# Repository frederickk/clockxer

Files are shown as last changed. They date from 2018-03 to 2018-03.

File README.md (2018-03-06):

Clockxer
======

### An analog sync clock with adjustable BPM and 2-channel passive mixer.

------
#### 💾 Software

Under the hood is an [Arduino Uno](https://store.arduino.cc/usa/arduino-uno-rev3) along with a [SparkFun Spectrum Shield](https://www.sparkfun.com/products/13116) ~~(for audio analysis)~~. Both of these are probably a bit overkill given the way I'm implementing things. But, I'm more comfortable with software than hardware and I had an Arduino sitting idle on my desk.

The Arduino handles the logic for reading the values from the rotary encoder ~~and analyzing the audio data for beat detection~~ (TODO 😄). There are two libraries that I leaned on for this.

**Third party libraries**
* [MSGEQ7](https://github.com/NicoHood/MSGEQ7) which makes it much easier to pull audio data from the [MSGEQ7](https://www.sparkfun.com/datasheets/Components/General/MSGEQ7.pdf) chips which are part of the [Spectrum Shield](https://www.sparkfun.com/products/13116).
* [Adafruit LED Backpack](https://github.com/adafruit/Adafruit_LED_Backpack) which handles all of the magic to display BPM value on the segment display.
* [Protothreads library](https://code.google.com/archive/p/arduinode/downloads) A library for manaing [protothreads](http://harteware.blogspot.com/2010/11/protothread-powerfull-library.html) for Arduino.

------
#### 🎛️ Hardware

The hardware for this is pretty simple to put together. However, I can nearly guarantee that the way I've done it is not the most efficient way. For example, the [Spectrum Shield](https://www.sparkfun.com/products/13116) is a bit overkill and I could have use a singular MSGEQ7 IC. Equally, the Arduino itself is probably unnecessary for an actual electrical engineer. If you have suggestions, make a [pull request]() 🙏. Within the [hardware]() folder you'll find [Fritzing]() schematic files (or consult the JPEG below).

| Line-in (source) | Line-in | BPM | Sync | Mix |
| --- | --- | --- | --- | --- |
| Input: This audio analyzed by the MSGEQ7 chips, passed through to the **sync** output, and merged with **line-in** input. | Input: is passed through and merged with **source** input. | Knob: Set BPM for **sync** output. Push to toggle whether **sync** output is active. | Output: A 5V PP signal for syncing analog devices to the given BPM. | Output: Merged audio (mono) signal of **source** and **line-in** inputs. |
| Volume: Adjust the volume of the **source** input. | Volume: Adjust the volume of the **line-in** input. | | | Volume: Adjust the volume of the **mix** output. |

**Schematic**
How to solder everything together.

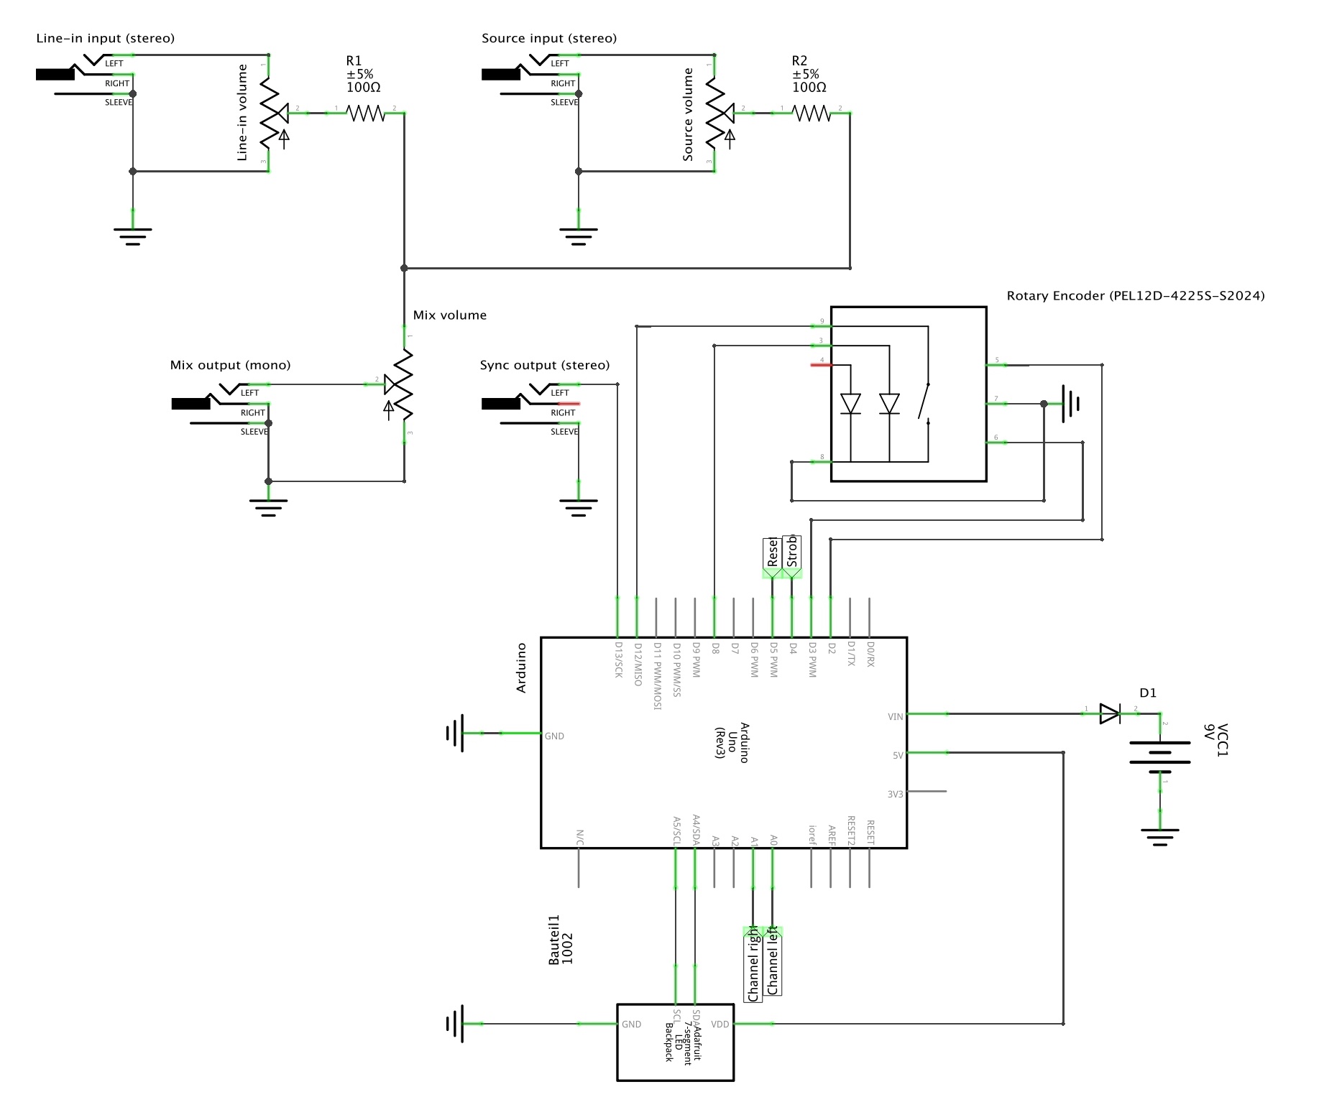
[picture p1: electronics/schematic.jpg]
Schematic


**Parts list**
The components for this project can be obtained through a few sources [Arduino](https://arduino.cc), [Adafruit](https://adafruit.com), [Sparkfun](https://sparkfun.com), and [DigiKey](https://digikey.com).

| Qty  | Part | Ref No. |
| ---- | --- | --- |
| 1 | Arduino Uno | |
| 1 | Spectrum Shield | [DEV-13116](https://www.sparkfun.com/products/13116) |
| 1 | Enclosure 119.5mm x 94mm x 42mm | [1590BBSBK](https://www.digikey.com/scripts/DkSearch/dksus.dll?Detail&itemSeq=251416092&uq=636536516904889851) |
| 1 | Rotary Encoder switch and LED | [PEL12D-4225S-S2024](https://www.digikey.com/scripts/DkSearch/dksus.dll?Detail&itemSeq=251416645&uq=636536516904889851) |
| 1 | Transparent knob | [COM-10597](https://www.digikey.com/scripts/DkSearch/dksus.dll?Detail&itemSeq=251417859&uq=636536516904899851) |
| 3 | 10k Logarithmic Potentiometer | [PDB181-K420K-103A2](https://www.digikey.com/scripts/DkSearch/dksus.dll?Detail&itemSeq=251416999&uq=636536516904889851) |
| 3 | Volume knob | [1568-1606](https://www.digikey.com/scripts/DkSearch/dksus.dll?Detail&itemSeq=251417794&uq=636536516904889851) |
| 3 | 1/4" (6.35mm) Stereo input jack | [SC1317](https://www.digikey.com/product-detail/en/switchcraft-inc/112BX/SC1317-ND/1217816) |
| 1 | 4-Digit 7-Segment Display w/I2C Backpack | [1002](https://www.adafruit.com/product/1002) |
| 1 | 9V Connector | [36-232](https://www.digikey.com/product-detail/en/keystone-electronics/232/36-232-ND/303804) |
| 1 | 50V 1A Diode (1N4001) | [641-1310-1](https://www.digikey.com/product-detail/en/comchip-technology/1N4001-G/641-1310-1-ND/1979675) |

**Enclosure**

Of course you can use any enclosure you want, but I opted for a [diecast aluminium (black) case](https://www.digikey.com/product-detail/en/hammond-manufacturing/1590BBSBK/1590BBSBK-ND/3869214). It's compact (119.5mm x 94mm x 42mm), but still has plenty of room for the Arduino and a 9-volt battery. I've created a [base](https://www.tinkercad.com/things/crAZhWdCvB1-clockxer-enclosure-base) that sits inside the enclosure to keep the internal components in place. For mounting the 7 Segment display I've created a [cowling](https://www.tinkercad.com/things/hzLmspQi8GF-clockxer-led-cowling) to mask the terribly cut square hole.

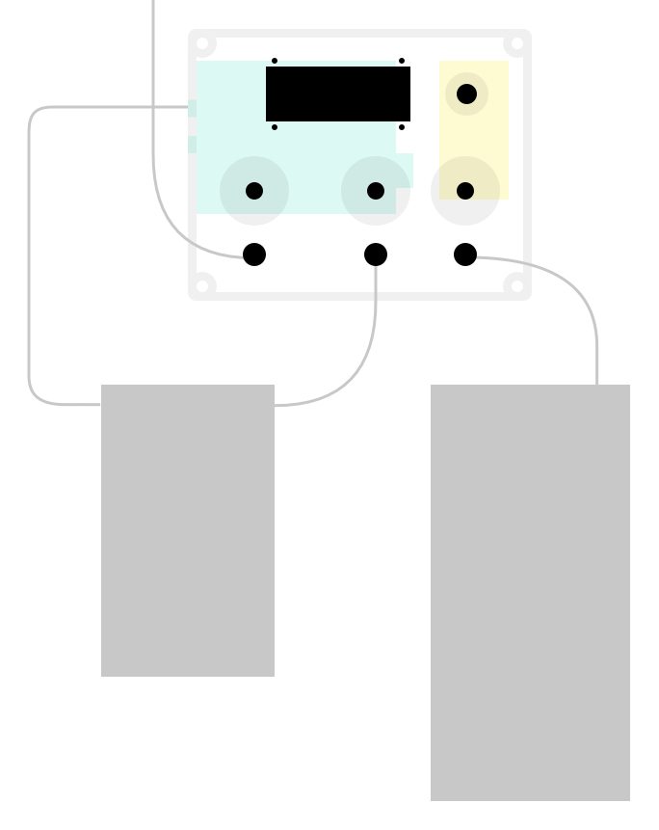
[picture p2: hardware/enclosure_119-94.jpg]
Enclosure layout


------
#### 🎩 Tip-of-the-hat

Without [Google](https://google.com) I wouldn't have stumbled across the following sites, which were helpful in a number of ways.

* [Electronoize Playshop: Dividers, Volume Controls, Mixers, Filters, Switches...](http://www.fluxmonkey.com/electronoize/passiveDividersFilters.htm)
* [Timer, Counter und Interrupts | heise Developer](https://www.heise.de/developer/artikel/Timer-Counter-und-Interrupts-3273309.html)
* [bildr  » Rotary Encoder + Arduino](http://bildr.org/2012/08/rotary-encoder-arduino/)
* [How to "Multithread" an Arduino (Protothreading Tutorial)](https://create.arduino.cc/projecthub/reanimationxp/how-to-multithread-an-arduino-protothreading-tutorial-dd2c37)
* [protothread, a powerfull library[sic]](http://harteware.blogspot.com/2010/11/protothread-powerfull-library.html)

------
#### 📜 License

[MIT](https://opensource.org/licenses/MIT)

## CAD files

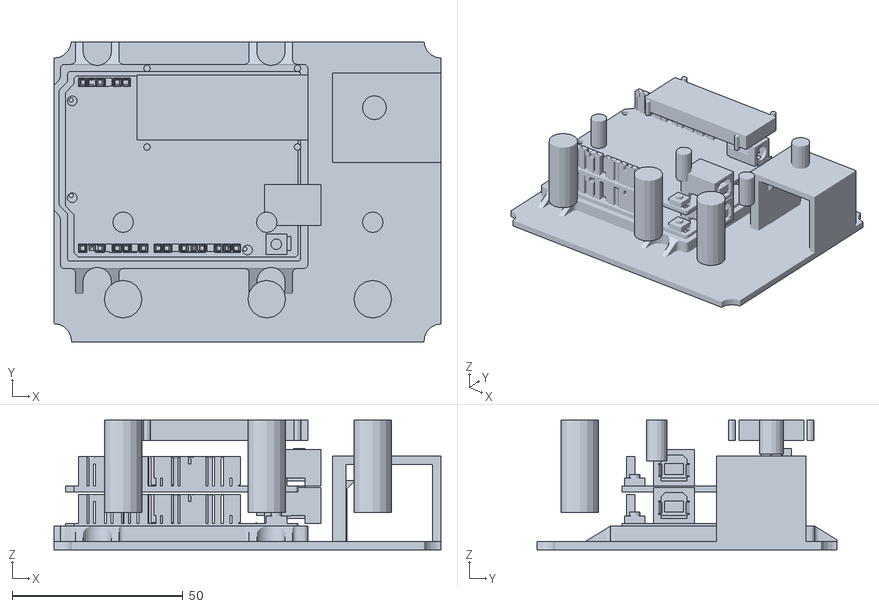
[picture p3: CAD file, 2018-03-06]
hardware/enclosure-base.stl
113.2 x 87.7 x 38.0

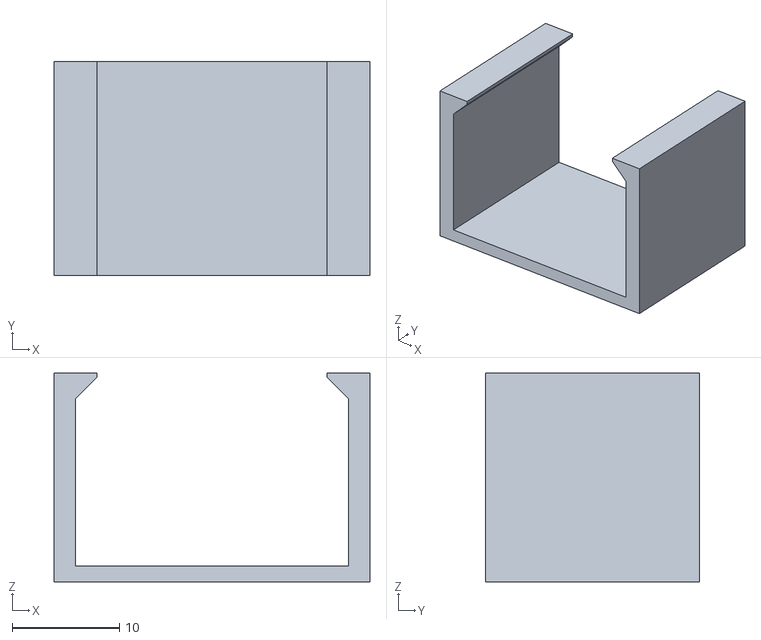
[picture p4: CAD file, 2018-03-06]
hardware/Models/9vClip_plain.stl
29.5 x 20.0 x 19.5

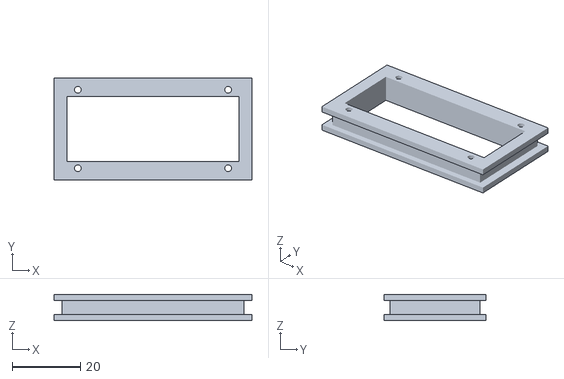
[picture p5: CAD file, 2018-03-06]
hardware/led-cowling.stl
58.0 x 30.0 x 7.70

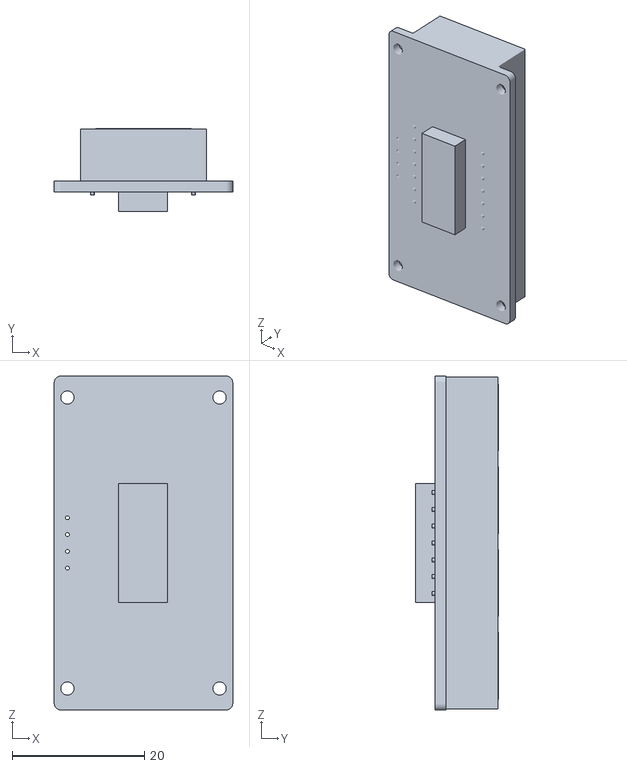
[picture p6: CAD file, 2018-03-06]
hardware/Models/adafruit_0_56_in_7-segment_display_backpack.stl
27.0 x 12.6 x 50.5

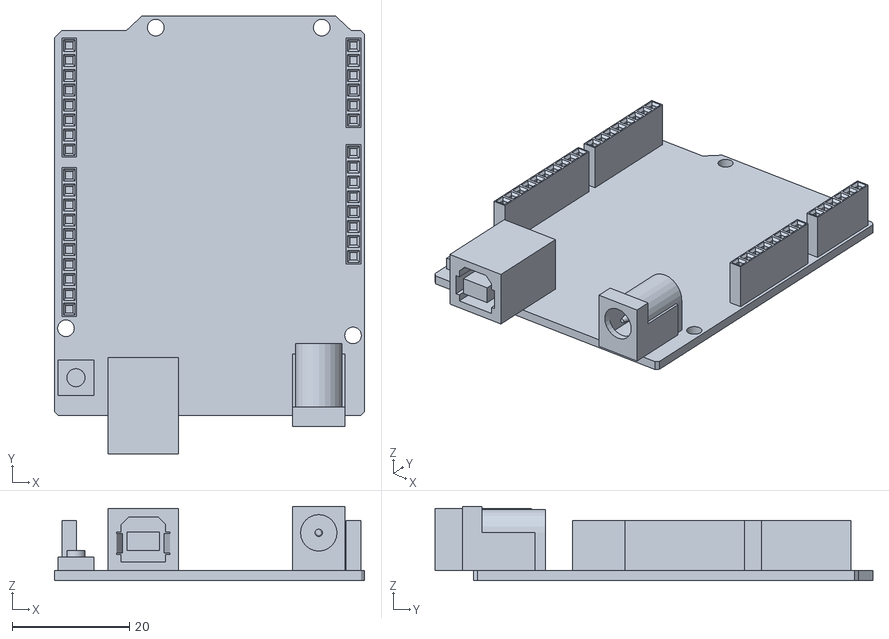
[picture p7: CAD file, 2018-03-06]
hardware/Models/Arduino_Reference_Model.stl
52.9 x 74.7 x 12.6

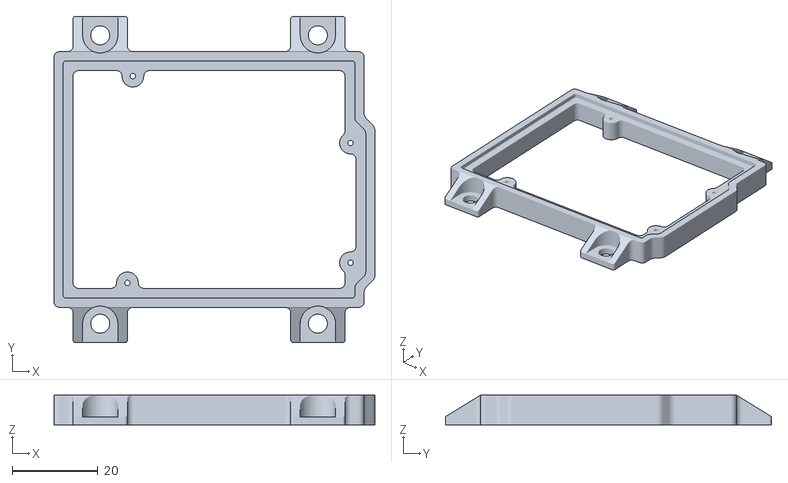
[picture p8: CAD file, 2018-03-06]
hardware/Models/UNO_R2_MOUNT.STL
74.9 x 76.2 x 6.99

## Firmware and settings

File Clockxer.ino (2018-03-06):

/**!
 * Clockxer
 *
 * Ken Frederick
 * ken.frederick@gmx.de
 * http://kenfrederick.de/
 *
 * Required 3rd Party libraries
 * https://github.com/NicoHood/MSGEQ7
 * https://github.com/adafruit/Adafruit_LED_Backpack
 * https://code.google.com/archive/p/arduinode/downloads
 *
 * License:
 * https://opensource.org/licenses/MIT
 *
 */



//-----------------------------------------------------------------------------
//
// Includes
//
//-----------------------------------------------------------------------------
#include "MSGEQ7.h"
#include "pt.h"
#include "RotaryEncoder.h"

// These two have been installed globally in your root Arduino/libraries folder
#include <Adafruit_GFX.h>
#include "Adafruit_LEDBackpack.h"



//-----------------------------------------------------------------------------
//
// Constants
//
//-----------------------------------------------------------------------------
// MSGEQ7
#define STROBE 4
#define RESET 5
#define CHANNEL_LEFT A0
#define CHANNEL_RIGHT A1

#define MSGEQ7_INTERVAL ReadsPerSecond(100)
#define MSGEQ7_SMOOTH 0 // Range: 0-255
#define BAND_LENGTH 7

// Rotary Encoder
#define BUTTON 12
#define ACTIVE_PIN 8
#define MIN_BPM 60 * 4
#define MAX_BPM 240 * 4

// Sync output
#define SYNC_PIN 13

// Protothread
static struct pt protothreadMain, protothreadSync;



//-----------------------------------------------------------------------------
//
// Properties
//
//-----------------------------------------------------------------------------
// MSGEQ7 IC with 7 different frequencies from range 0-255
// Bass ------------------Mid-----------------Treble
// 63Hz, 160Hz, 400Hz, 1kHz, 2.5kHz, 6.25KHz, 16kHz
CMSGEQ7<MSGEQ7_SMOOTH, RESET, STROBE, CHANNEL_LEFT, CHANNEL_RIGHT> MSGEQ7;

int LED[] = {9, 10, 11}; // Low, Mid, High

uint8_t freqMax[BAND_LENGTH];
byte band = 0;

// Rotary Encoder
RotaryEncoder rotary(BUTTON);
long ms = 1000;

// 7 Segment Display
Adafruit_7segment disp = Adafruit_7segment();



//-----------------------------------------------------------------------------
//
// Methods
//
//-----------------------------------------------------------------------------
void setup() {
  Serial.begin(9600);

  // Setup MSGEQ7/Spectrum Shield for readings
  MSGEQ7.begin();

  for (band = 0; band < BAND_LENGTH; band++) {
    // Setup array for max values
    freqMax[band] = 1;
  }

  // Setup rotary encoder for reading.
  rotary.init();
  rotary.setMinVal(60);
  rotary.setMaxVal(240);
  pinMode(ACTIVE_PIN, OUTPUT);

  // Setup sync pin signal
  pinMode(SYNC_PIN, OUTPUT);

  // Setup display
  disp.begin(0x70);
  disp.setBrightness(3);

  // Setup Protothreads
  PT_INIT(&protothreadSync);
}

void loop() {
  // Call rotary handlers
  rotary.encoderHandler();
  rotary.clickHandler();

  disp.print(rotary.getVal(), DEC);
//  disp.

  long ms = bpmToMs(rotary.getVal());
//  Serial.print("MS: ");
//  Serial.print(ms);
//  Serial.print(" ROTARY_ACTIVE: ");
//  Serial.println(rotary.isActive);

  // reset SYNC_PIN and ACTIVE_PIN before calling protothread method
  digitalWrite(SYNC_PIN, LOW);
  digitalWrite(ACTIVE_PIN, LOW);

  syncHandler(&protothreadSync, ms);

  // Write to display
  disp.writeDisplay();
}

/**
 * Handler for syncing; audio pulse and LED flash
 * @param  pt       pt address operator
 * @param  interval rate in MS to repeat function
 */
static int syncHandler(struct pt *pt, int interval) {
  static unsigned long timestamp = 0;
  PT_BEGIN(pt);
  while(1) {
    PT_WAIT_UNTIL(pt, millis() - timestamp > interval);
    timestamp = millis();

    if (rotary.isActive == 1) {
      if (digitalRead(ACTIVE_PIN) == HIGH) {
  //      disp.drawColon(fals);
        digitalWrite(ACTIVE_PIN, LOW);
        digitalWrite(SYNC_PIN, LOW);
      } else {
  //      disp.drawColon(true);
        digitalWrite(ACTIVE_PIN, HIGH);
        digitalWrite(SYNC_PIN, HIGH);
      }
    }

  }
  PT_END(pt);
}

/**
 * Frequency analyzer
 */
void analyze() {
  // Analyze without delay every interval.
  bool isNewReading = MSGEQ7.read(MSGEQ7_INTERVAL);

  if (isNewReading) {
    for (band = 0; band < BAND_LENGTH; band++) {
      // Read frequency value
      uint8_t freq = MSGEQ7.get(band);

      // reduce noise
      freq = mapNoise(freq);

      // Keep track of peak value.
      if (freq > freqMax[band]) {
        freqMax[band] = freq;
      }

//      uint8_t val = normalizePWM(freq, freqMax[band]);

      // Output PWM signal (LED) to the music beat
//      analogWrite(LED[band], val);

//      Serial.print(" --- ");
//      Serial.print(band);
//      Serial.print(" --- ");
//      Serial.println("Freq ");
//      Serial.println(freq);
//      Serial.println(" --- ");
//      Serial.print(freqMax[band]);
//      Serial.print(" --- ");
//      Serial.println(val);
    }
  }
}

/**
 * @param  val        the input value
 * @param  max        the maximum value
 * @return normalized value e.g. betwen 0-255
 */
uint8_t normalizePWM(uint8_t val, uint8_t max) {
  return (uint8_t) map(val, 0, max, 0, 255);
}

/**
 * Convert BPM value into milliseconds.
 * @param  bpm
 * @return milliseconds
 */
unsigned int bpmToMs(unsigned int bpm) {
  return 60000 / bpm;
}

//
//bpmToHz(unsigned int bpm) {
//  return bpm * 0.01666667
//}

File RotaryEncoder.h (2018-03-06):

#ifndef _ROTARY_ENCODER
#define _ROTARY_ENCODER

#if (ARDUINO >= 100)
  #include "Arduino.h"
#else
  #include "WProgram.h"
#endif


//template <uint8_t msbPin, uint8_t lsbPin, uint8_t buttonPin>
class RotaryEncoder {
  private:
    uint8_t buttonPin_;
    // Encoder must use pins 2 and 3
    // MSB = most significant bit
    uint8_t msbPin_;
    // LSB = least significant bit
    uint8_t lsbPin_;

    unsigned int multiplier_;

    volatile long valPrev_;
    int maxVal_;
    int minVal_;
    byte state_;
    byte statePrev_;
    boolean isToggled_;


  public:
    volatile long val;
    byte isActive;

    // Constructor
    RotaryEncoder(uint8_t buttonPin = 12) {
      msbPin_ = 2;
      lsbPin_ = 3;
      buttonPin_ = buttonPin;

      // TODO(ken.frederick): If I set the initial val at 0, and then later
      // call setMinVal, it doesn't update the val...
      val = 60 * 4;
      valPrev_ = val;

      state_ = 1; // true
      statePrev_ = state_;
      isToggled_ = true;

      isActive = 0;
    }

    // Deconstructor
    ~RotaryEncoder() {
    }

    /**
     * Init/setup pins and encoder handler.
     */
    void init() {
      // Set default multiplier value.
      setMultiplier(4);

      // Set default minimum and maximum values.
      setMinVal(60);
      setMaxVal(240);

      // Setup pins for reading Rotary Encoder values.
      pinMode(msbPin_, INPUT);
      pinMode(lsbPin_, INPUT);
      digitalWrite(msbPin_, HIGH);
      digitalWrite(lsbPin_, HIGH);

      // Activate pins for Rotary Encoder button
      pinMode(buttonPin_, INPUT);
      digitalWrite(buttonPin_, HIGH);

      // Can't call attachInterrupt from within class :(
      // https://forum.arduino.cc/index.php?topic=480721.0
      // attachInterrupt(0, encoderHandler, CHANGE);
      // attachInterrupt(1, encoderHandler, CHANGE);
    }

    /**
     * Handler for encoder values.
     */
    void encoderHandler() {
      int MSB = digitalRead(msbPin_);
      int LSB = digitalRead(lsbPin_);

      // converting the 2 pin value to single number
      int encoded = (MSB << 1) | LSB;
      int sum = (valPrev_ << 2) | encoded;

      if(sum == 0b1101 || sum == 0b0100 || sum == 0b0010 || sum == 0b1011) {
        if (val < maxVal_) {
          val++;
        } else {
          val = maxVal_;
        }
      }
      if(sum == 0b1110 || sum == 0b0111 || sum == 0b0001 || sum == 0b1000) {
        if (val > minVal_) {
          val--;
        } else {
          val = minVal_;
        }
      }

      // store this value for next time
      valPrev_ = encoded;
    }

    /**
     * Handler for button click.
     */
    void clickHandler() {
      state_ = digitalRead(buttonPin_);

      if ((state_ != statePrev_) && (state_ == 1)) {
        if (isToggled_) {
          isActive = 1;
          isToggled_ = !isToggled_;
        } else {
          isActive = 0;
          isToggled_ = !isToggled_;
        }
      }

      // save the current state_ as the last state_, for next time through the loop
      statePrev_ = state_;
    }

    /**
     * Multiplier to improve accuracy of encoder value
     */
    void setMultiplier(int val) {
      multiplier_ = val;
    }

    /**
     * Maximum value for encoder.
     */
    void setMaxVal(int val) {
      maxVal_ = val * multiplier_;

      if (val >= maxVal_) {
        val = maxVal_;
        valPrev_ = val;
      }
    }

    /**
     * Minimum value for encoder.
     */
    void setMinVal(int val) {
      minVal_ = val * multiplier_;

      if (val <= minVal_) {
        val = minVal_;
        valPrev_ = val;
      }
    }

    /**
     *
     */
    volatile long getVal() {
      return (val / multiplier_);
    }
};



#endif
